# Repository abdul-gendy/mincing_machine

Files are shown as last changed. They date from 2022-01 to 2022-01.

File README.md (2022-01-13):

# mincing_machine
Autodesk fusion 360 assembly of a mincing machine, along with a CAE analysis of some parts in the assembly and a CAM setup for some parts as well

## CAD:
<p align="center">
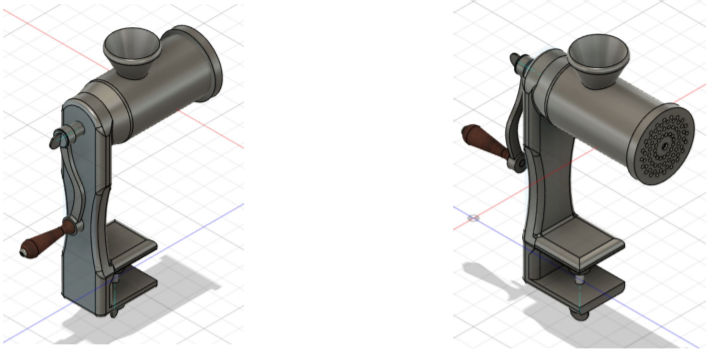
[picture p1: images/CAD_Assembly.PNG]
  
</p>

<p align="center">
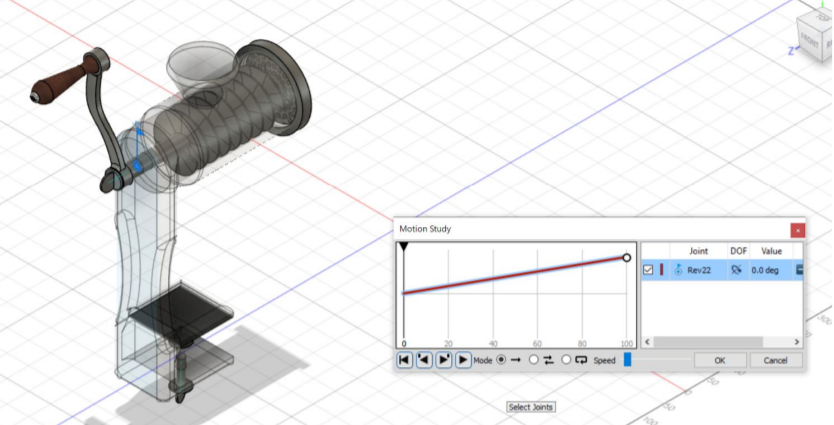
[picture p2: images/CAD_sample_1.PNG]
  
</p>

## CAE:
<p align="center">
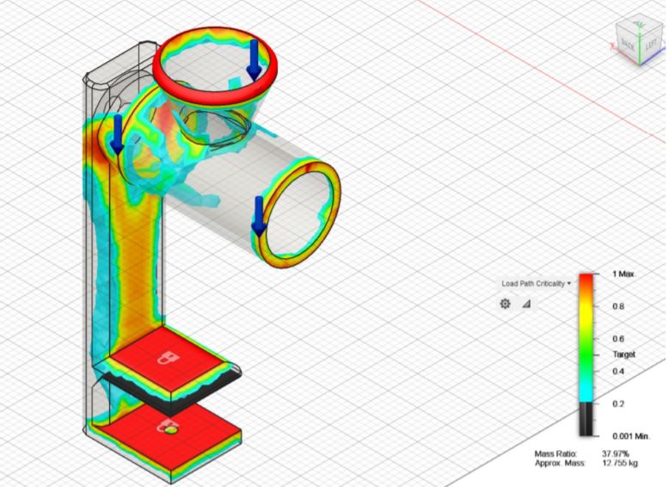
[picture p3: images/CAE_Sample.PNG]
  
</p>

## CAM:
 <p align="center">
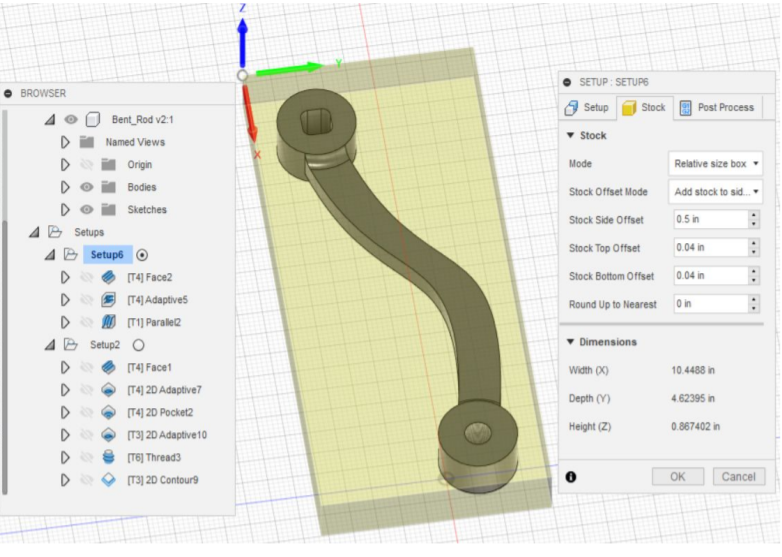
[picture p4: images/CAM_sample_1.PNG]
  
</p>

 <p align="center">
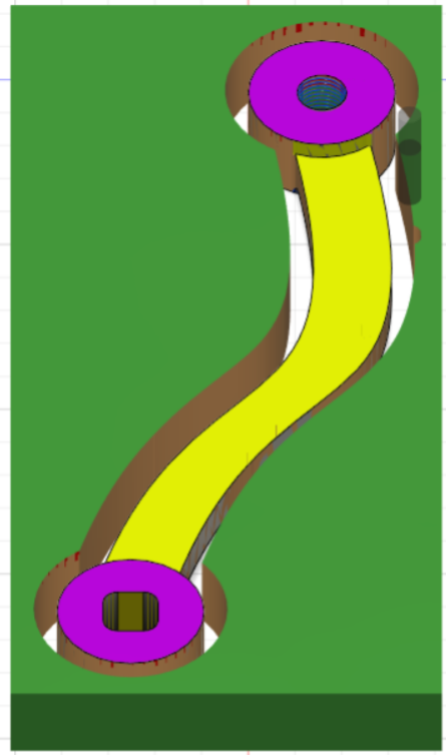
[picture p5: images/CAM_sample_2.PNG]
  
</p>

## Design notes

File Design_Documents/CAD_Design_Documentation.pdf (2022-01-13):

## MECH ENG 4Z03 Design Project

## Group 40

Name | Student Number | Email
Mark Danial | 400066296 | daniam1@mcmaster.ca
Abdulrahman Elgendy | 400051947 | elgendya@mcmaster.ca
Omar Mouftah | 400080124 | mouftaho@mcmaster.ca

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
## Introduction

The assembly we decided to model was that of a meat grinder. We chose this specific tool as it is something simple and basic that many families have, but also is a great example of basic mechanical systems and how they work together. The intended function of the meat grinder is to take some sort of input (usually meat, but can also be vegetables and lentils), and to grind the input together so that it comes out in a soft and ground consistency. The way this works is the user would input the food into the funnel at the top, and rotate the handle which is connected to the auger inside. The auger will then proceed to grind the food together, gradually being pushed towards the end of the tunnel where it will be cut up by a cutting star (or in our case, ninja star). The food then proceeds to get pushed out of the shaping plate at the end, which further breaks down the food into a softer, more grounded consistency. We chose to make most of our design out of stainless steel, as it provides the strong reliable support one can expect from steel but also rusts a lot slower and is easier to clean. These are attributes we deemed important when choosing the material of our meat grinder.

## Design Components Breakdown

Handle

When designing the handle, our main concern was the users comfort. To ensure a comfortable handle, we decided to make it out of mahogany so it has a softer touch and will not get slippery if the user has sweaty hands. The handle was designed to give the user some free space to move their hand while also not wasting too much space, and to provide a solid grip as the user’s main interaction will be with the handle. The modeling was fairly simple. We decided what the dimensions of the handle we wanted were and we drew circles and lines to make a 2D face, then revolved to get the desired shape of the handle.

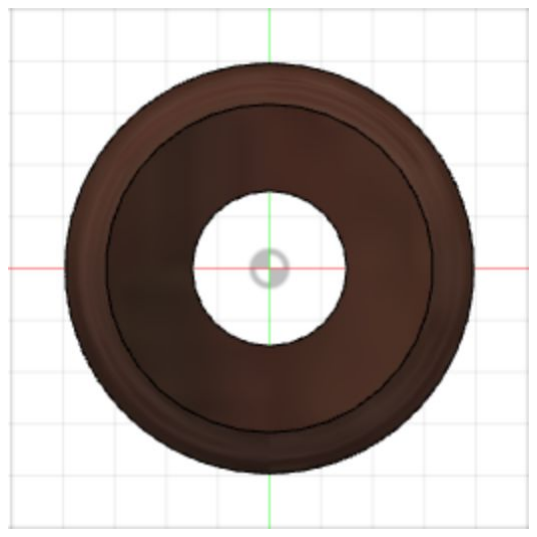
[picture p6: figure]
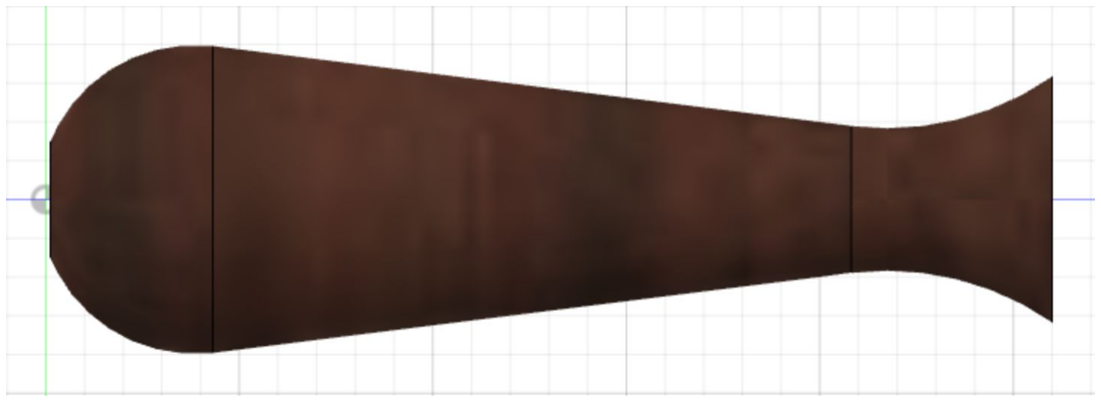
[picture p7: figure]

Handle Pin

The handle pin was a simple part that was needed to connect our handle with our handlebar. It is a simple screw with a thread only at the end of it, this way it can be slid through the wooden handle and screws onto the handlebar. We used a flat head on the screw as it simplifies the design while also getting the desired results. Modelling was simple with just two circle extrusions, a thread, a fillet, and a rectangular extrusion to make the flat head.

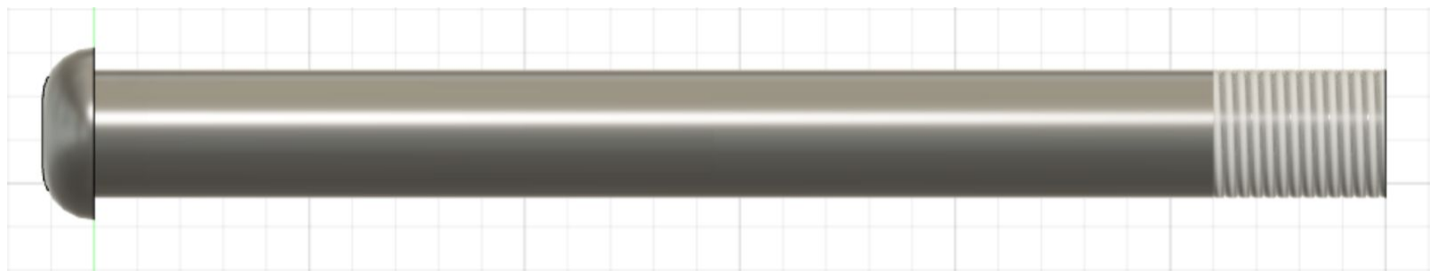
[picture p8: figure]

Handle Bar

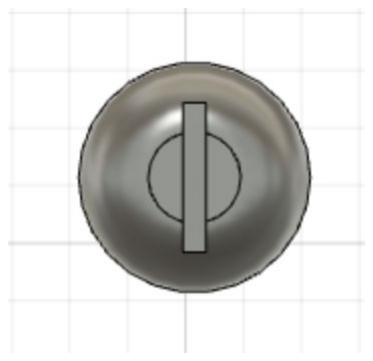
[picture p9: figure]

Next is the handle bar, which is used to connect the handle (through the handle pin) to the auger. This way we are able to translate the rotational motion of the handle to the auger. On the bottom end of the handle bar, the handle pin is screwed into it to connect the handle, while at the top end, the auger’s rounded square end is inserted into it which is connected to the pin. After deciding the length, all that was left was to connect the circular parts at the top of the bottom. A thread was added in the bottom section so that the handle pin can connect the handle with the handlebar. We added fillets on the handlebar to reduce stress concentration, while also adding a sense of style. We decided to use a curved shape to provide some style, which was done by using the fit-point-spline tool.

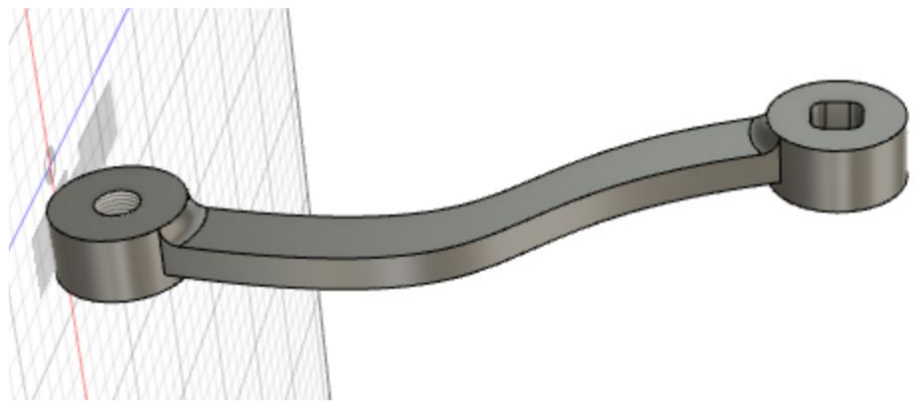
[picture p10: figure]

Auger

Next is the auger, which is the part that the user has the least interaction with but is also the most crucial for the operation of the meat grinder. On one end of the auger, we have the rounded square end that is connected with the handle bar, which is then screwed together using the pin, and the other end lies in the shaper so it has support. Designing the auger was a complicated process as Fusion 360 does not have a helix tool so a more roundabout method was needed. The steps to model the auger were as follows:

1) Extrude Circle to make a cylinder
2) Create a coil (square cross section) with the length of the desired auger with the same diameter as the cylinder, also chose how many revolutions we wanted
3) Create a plane on an angle which was based off of the end of the coil, so that we can draw a rectangle on it which soon become the tooth of the auger
4) Use the “Path + Guide Surface” type Sweep tool along the path of the edge of the coil, which then gives shape to the rectangle we drew earlier
5) Designing the auger itself is done now, just design the endings so that the auger may connect with its counterparts as required

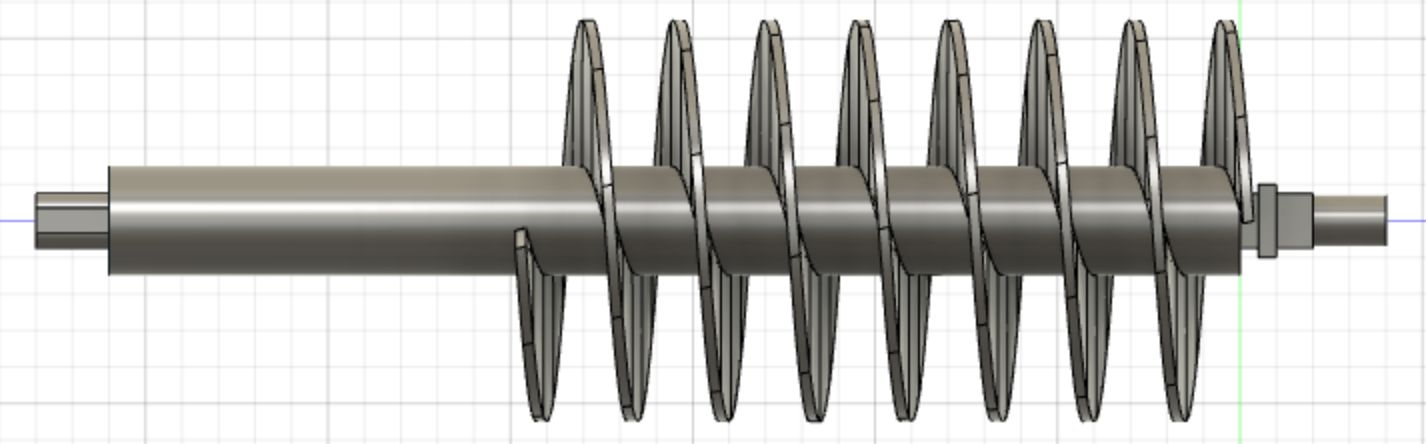
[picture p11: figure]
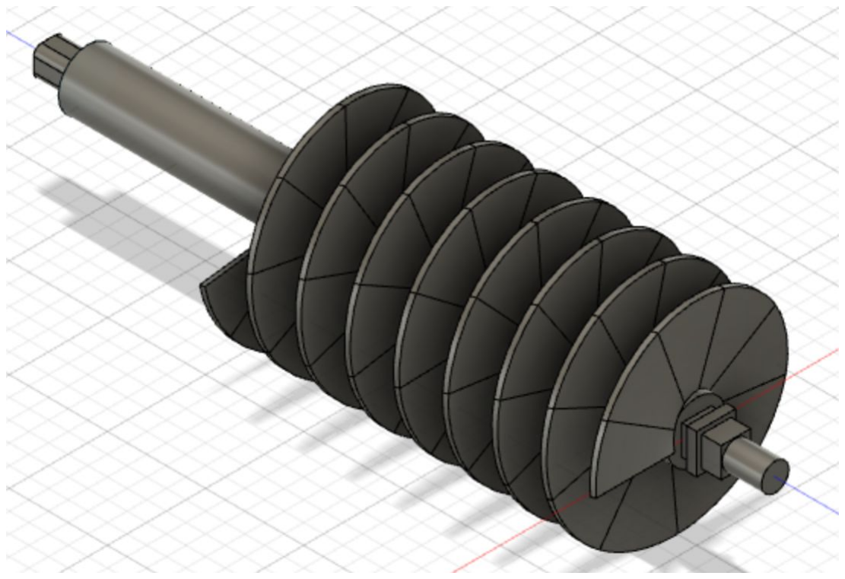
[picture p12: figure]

Pin & Clamp Pin

The pin and the clamp pin are both very similar parts. The key difference is sizing and that the clamp pin has a flat circular surface at the end of the screw, which is meant to get pressed upward onto the surface to provide support for the meat grinder. The pin is used to hold the auger and the handlebar together. Modeling these was very straight forward, we used a few circular extrusions and a fillet, with a thread at the end.

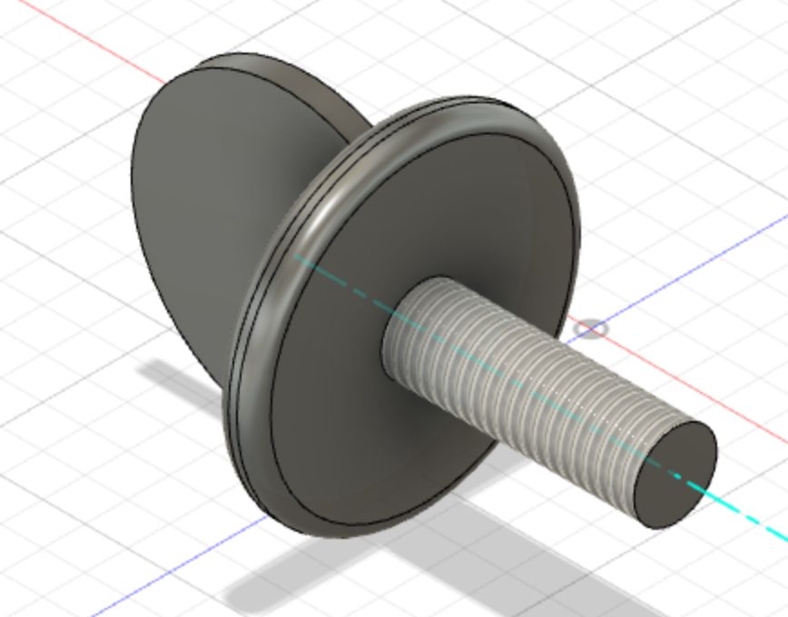
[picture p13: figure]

Body

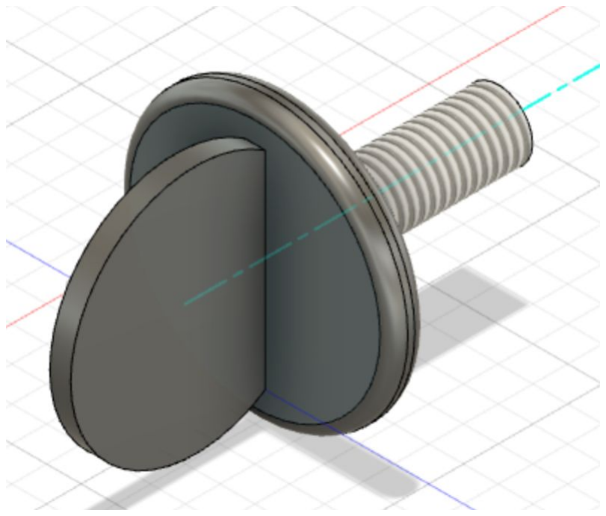
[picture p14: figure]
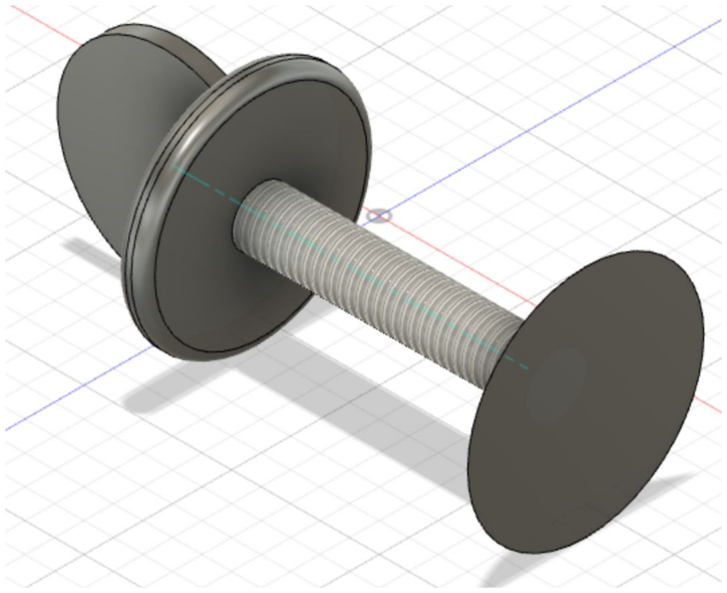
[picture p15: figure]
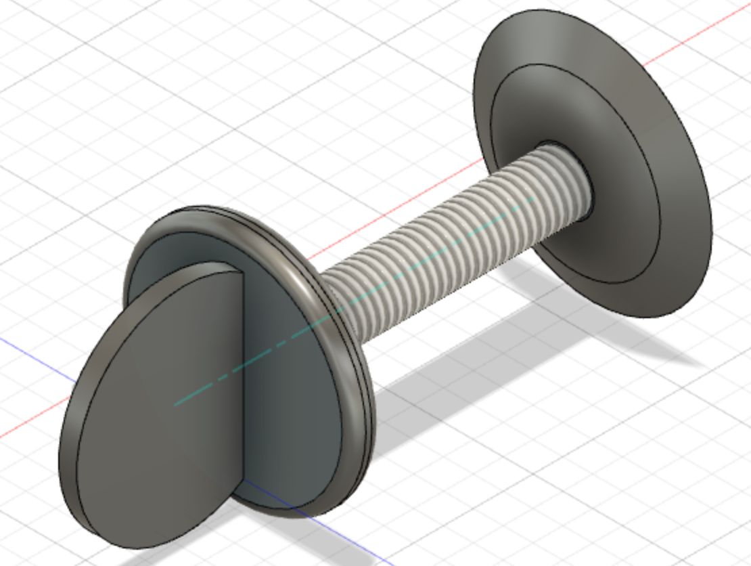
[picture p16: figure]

Next we have the body, which is the largest component in the design. The body connects all the pieces together and houses the auger in the grinding chamber. The body clamps onto the table with the teeth on the top surface and the clamp pin at the bottom. At the top of the grinding chamber there is a cone that the meat is fed into, which then falls into the auger for grinding. At the end of the grinding chamber we have a thread which is used to screw the shaping face onto the body. The body was designed using simple extrusions of basic shapes like circles, rectangles, and triangles (for the teeth), and some lofts to make the grinding chamber and the cone. We chose to add fillets around the body to reduce any edges that may cause cuts since the user will be holding onto the body a lot, and this will also reduce stress concentration.

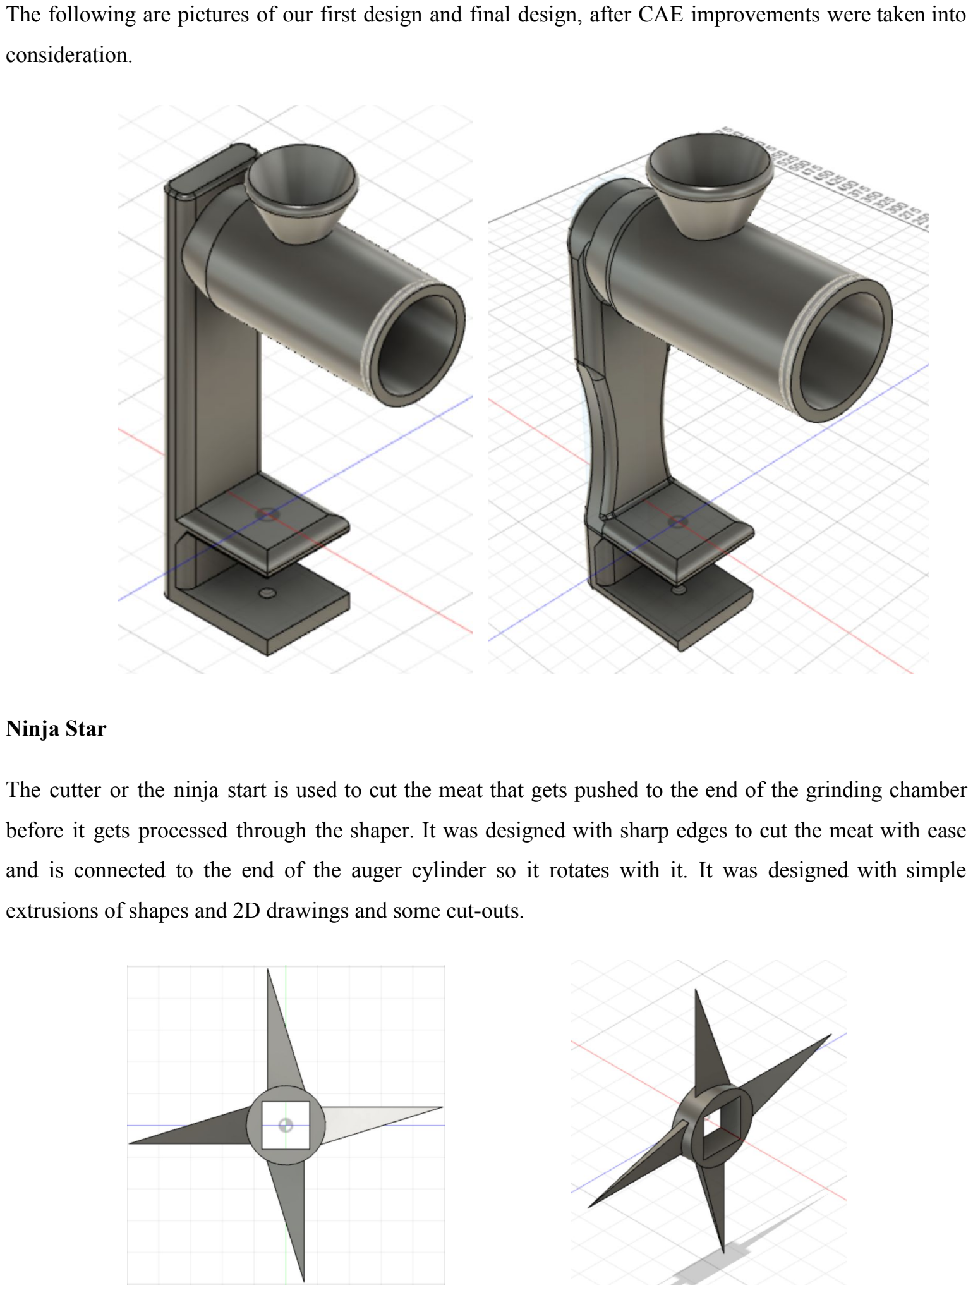
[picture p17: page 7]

The following are pictures of our first design and final design, after CAE improvements were taken into consideration.

Ninja Star

The cutter or the ninja start is used to cut the meat that gets pushed to the end of the grinding chamber before it gets processed through the shaper. It was designed with sharp edges to cut the meat with ease and is connected to the end of the auger cylinder so it rotates with it. It was designed with simple extrusions of shapes and 2D drawings and some cut-outs.

Shaper

Lastly, we have the shaper. The shaper is screwed onto the body at the end of the grinding chamber. The meat is pushed through the grinding chamber by the auger, cut by the ninja star, and then pushed out of the shaper. This is the last phase of processing of the meat and breaks it down into a more refined, ground material. It was designed with simple circle extrusions and a thread on the inner side

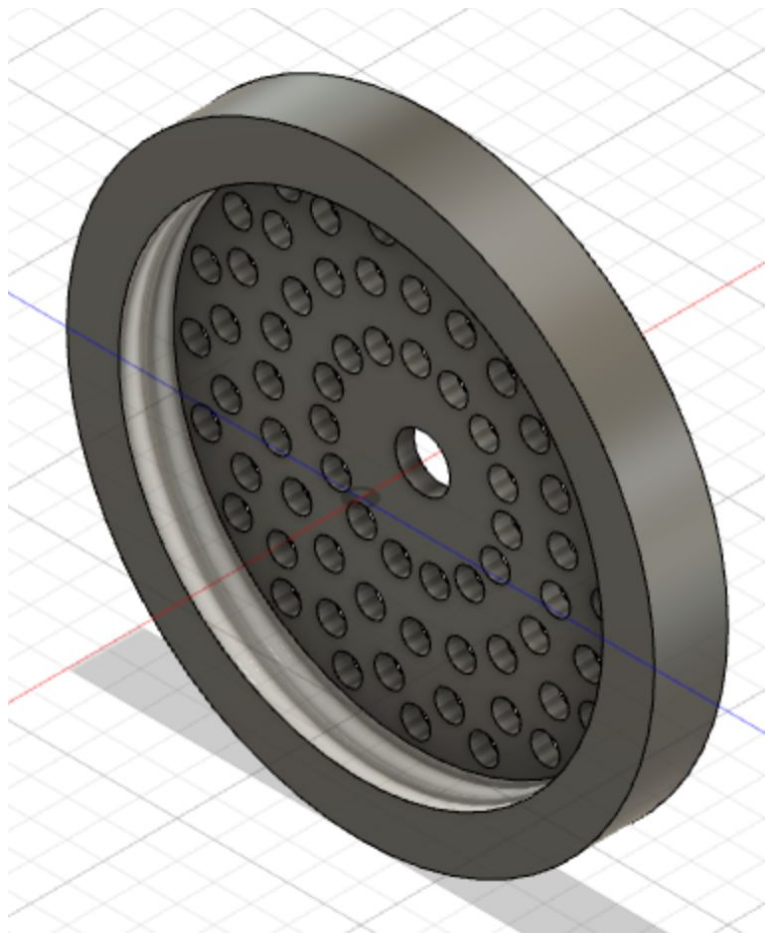
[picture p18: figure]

## Future Improvements

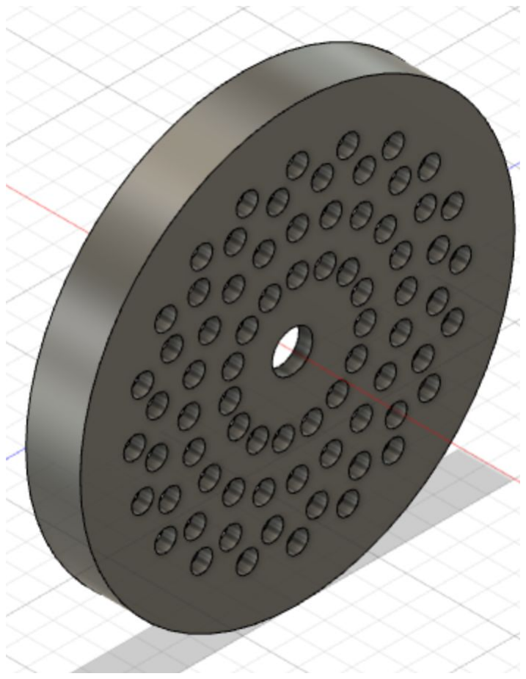
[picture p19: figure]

For a future iteration of the design, we could choose to change several things about the design. One of the things we can look to improve is the size of the grinding chamber. It can be made to hold more/less meat based on feedback from possible users. Another thing we could change is the shapers; We can choose to add more shapers so that the user has the option to choose between different processing sizes for the shaper. Another thing we can look to improve is the handlebar. By choosing a different length and design, we can find an optimal design which would maximize torque and reduce the effort needed by the user.

## Assembly and Dynamic Simulation:

Assembly

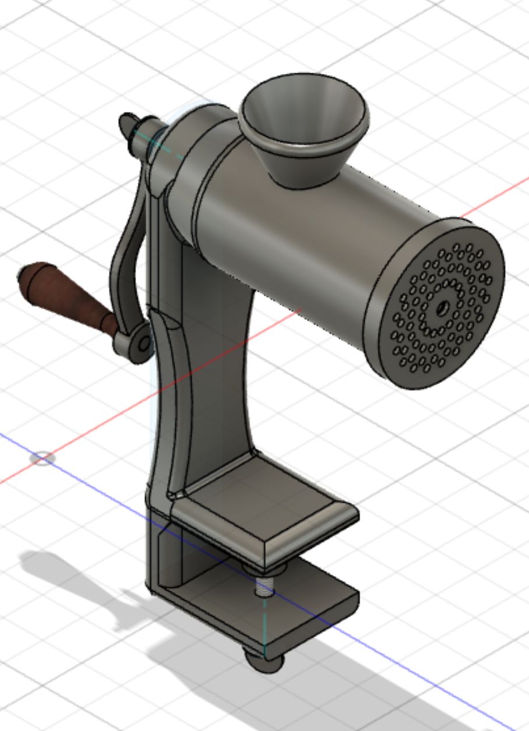
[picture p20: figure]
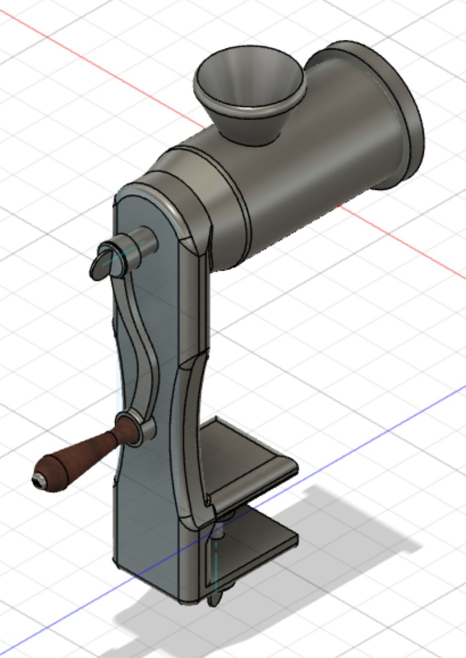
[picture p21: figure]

The views above are of the final assembly with all parts in appropriate positions using joints. A combination of rigid and revolve joints were used in order to ensure proper behaviour when the handle rotates. The handle is linked to the handle pin through a rigid joint to ensure that the pin rotates whenever the handle is moved. There is another rigid joint between the handle pin and the handle bar which is used for the same reason as the first rigid joint. Similarly another rigid joint links between the handle par and the pin. The auger is linked to the body using a revolve joint and to the pin using a rigid constraint, this ensures when the handle moves all the corresponding parts move accordingly including the handle pin, the handle bar, the pin, and the auger. The auger then is linked to the ninja star through another rigid constraint to maintain the same rotation motion. The shaper is linked to the body using a rigid constraint to ensure it does not rotate with the rest of the mechanism. The clamp pin is another part that is linked to the body through a revolve joint to enable the pin from settling in its position based on the width of the table.

Dynamic Simulation

The simulation is available in the motion study section of the assembly and involves moving the main revolve joint that corresponds to the revolving mechanism and observing how parts move accordingly. The screenshots below illustrate the simulation performed. The body is made transparent to a certain degree in order to show the motion of auger and the ninja star inside the meat grinding chamber portion of the body.

Starting Position with handle angle 0 degrees

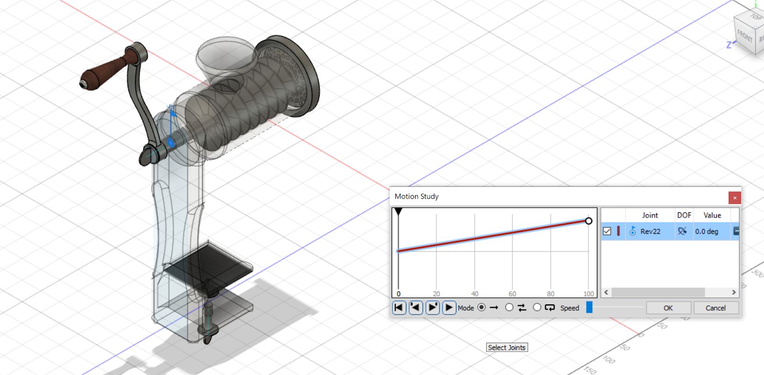
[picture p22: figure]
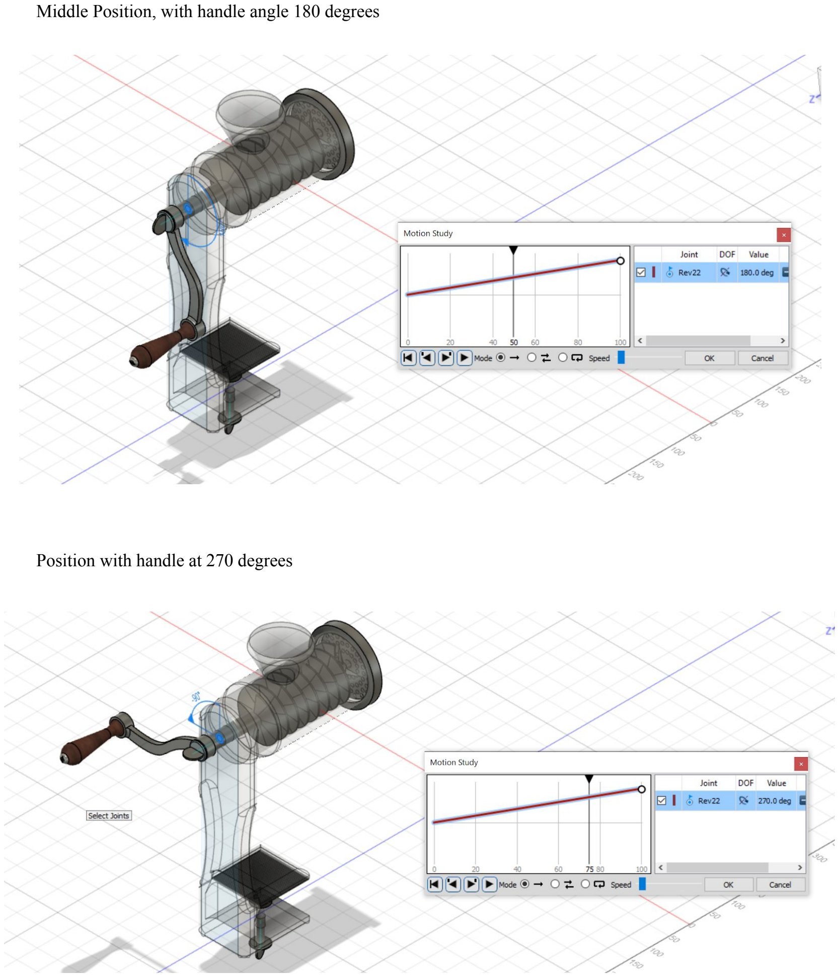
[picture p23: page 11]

Middle Position, with handle angle 180 degrees

Position with handle at 270 degrees

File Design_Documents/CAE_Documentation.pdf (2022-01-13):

## Computer Aided Engineering

Part 1 - Body

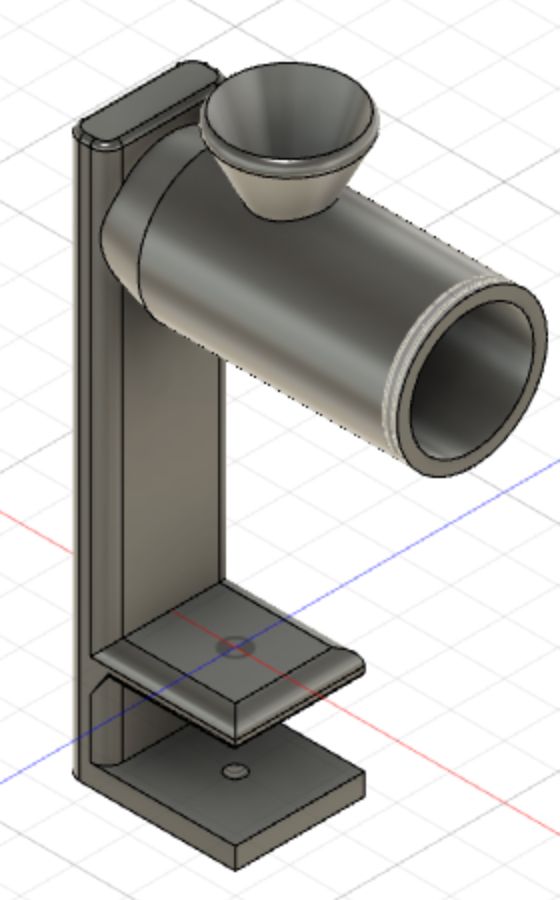
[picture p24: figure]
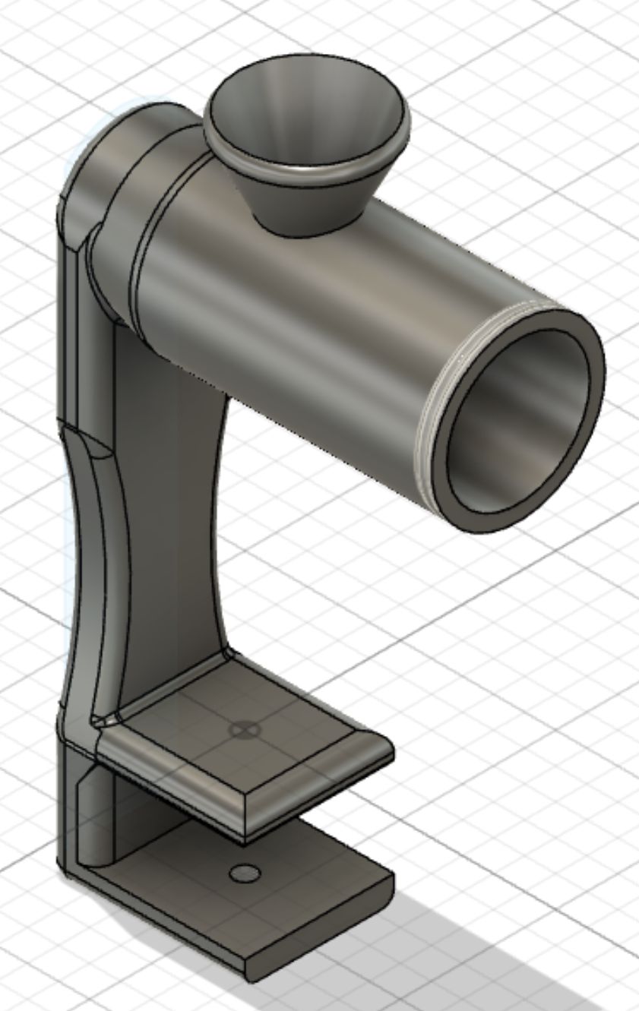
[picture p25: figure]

The body of the meat grinder is one of the most critical parts as it contains the entire mechanism and is exposed to the most loads due to its size. The design on the left was the initial design for the body. While material usage and optimization were taken into account during the preliminary design stage, the CAE analysis revealed that there were still areas of improvements through material reductions. The mass for the initial body part was around 34 kg, however, after shape optimization and reduction of unneeded material the mass for the modified body part was 30 kg which is a reduction of more than 12 %. The loading for the part was over exaggerated at 1500 N which is an arbitrary heavy load which the body of the meat grinder is unlikely to get exposed to. The loads were applied at three areas, the first and second are at the beginning and end of the grinding chamber and are placed to simulate a user's hand applying a force to keep the body in place while grinding. The third load is to simulate the load resulting from the ungrinded meat in the cone area of the body. In addition, fixed constraints are placed on the two bottom faces of the body as they will be secured to the table using the clamp pin.

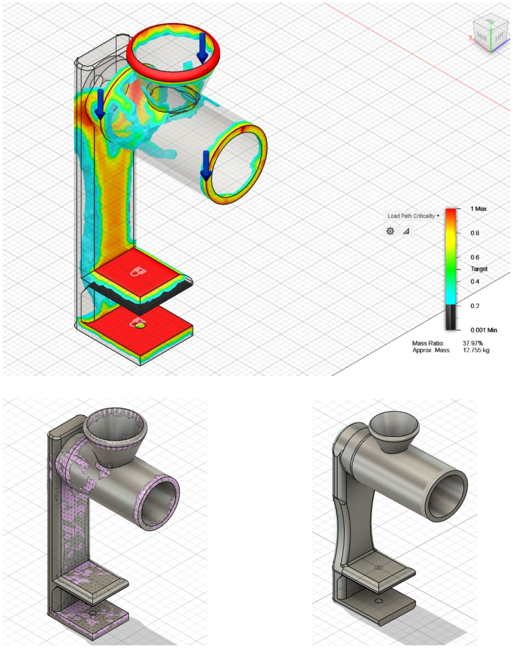
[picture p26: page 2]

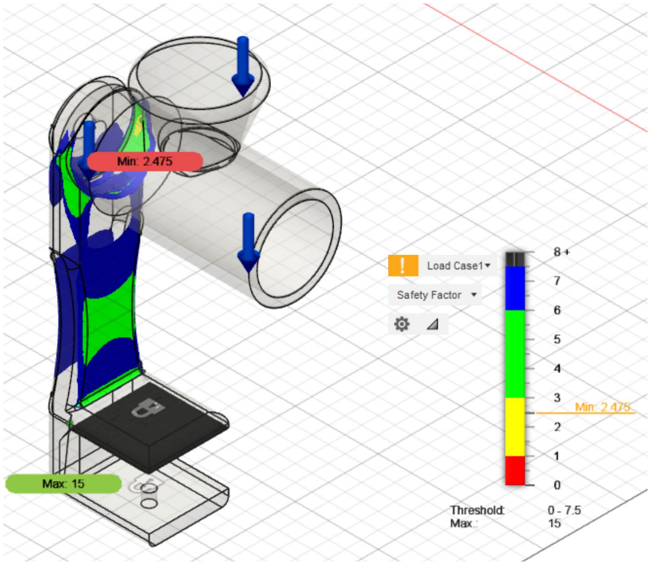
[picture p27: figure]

As seen from the results of the stress analysis, the material reduction did not affect the structural integrity of the body as it was able to handle the over estimated load of 1500 N with a minimum safety factor of safety of 2.475 which is suitable for a product that is not safety critical like a meat grinder. The loads are overestimated in order to test how the part would handle extreme loads after the part’s optimization.

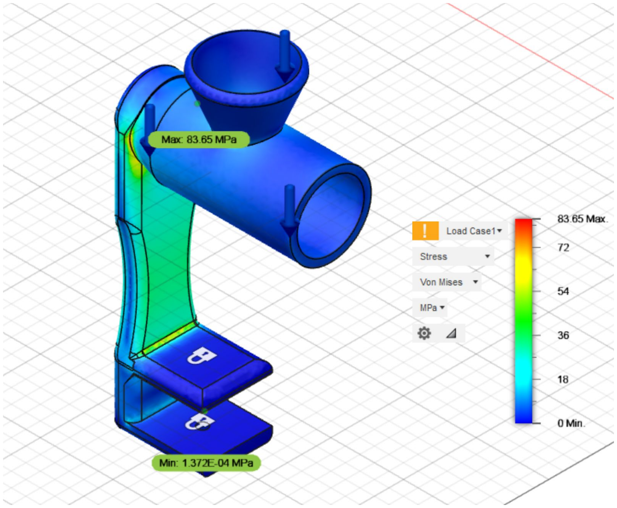
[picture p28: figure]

The von mises stress chart confirms the results from the safety factor chart as it shows maximum stress at the edge where the grinding chamber meets the remainder of the body. This edge is expected to have the maximum stress due to part geometry and the location the load is placed at. An improvement in the design would be changing the force at that edge to cover a larger area and thus reduce the stress concentration on that edge, however taking into account the excessive load that the test is placing on the part, the factor of safety and the maximum von mises stress seem to be within acceptable levels.

Part B - Shaper

While the shape optimization analysis was useful when conducted on the body part of the assembly the shaper is an example of a part which the shape optimization simulation was not useful and did not result in a change in the part design. The load that the shaper experiences is a result of all the meat being pushed by the auger. This load was simulated by an over estimated by a constant 1500 N force over the inside face of the shaper. The fixed constraint associated with the shaper is on the inside area that is fixed to the body part and thus does not move as part of the rotating mechanism.

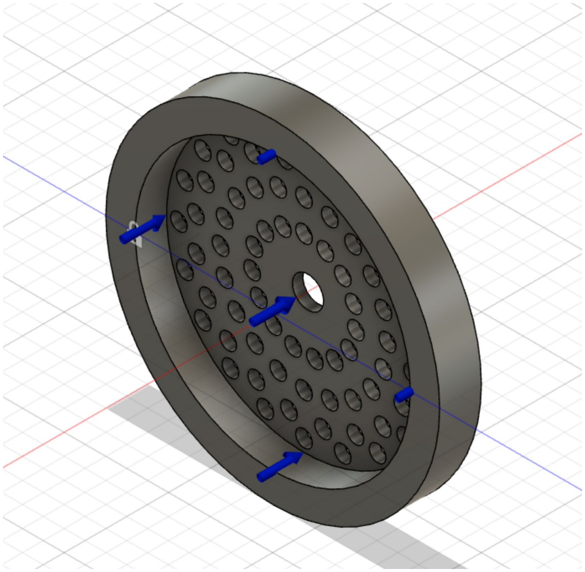
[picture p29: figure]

The results of the shape optimization simulation are the following:


This shows that the material that is not needed according to the simulation is required in order to assemble the shaper with the body part and as any material removal form the edge might affect the neshing between the threads in the shaper and the threads on the end of the grinding chamber in the body part. Furthermore, the amount of material to be removed based on the simulation results will not be significant enough to justify removing it from an economic standpoint and as a result a decision was made to keep the part in its initial form and perform the stress analysis on the preliminary design.

The stress analysis was done using the same load and constraints used in the shape optimization analysis. The load was also over exaggerated at 1500 N in order to simulate a very excessive condition on the part. The shaper part performed very well under the experienced load as the minimum factor of safety was 7.4 which means that the part can handle much higher loads than the simulated 1500 N. The charts below show the effect of the load in adjusted view to overstate the deformation of the part under the load. This analysis shows that the part in its initial format without modification was able to handle the forces that the part will be exposed to.


The von mises analysis shows that the maximum stress occurs at the holes of the shaper which is a result of the force from the meat hitting the sharp edge of the shaper to be cut into the appropriate shape. The von mises chart shows that even that those sharp edges exist for meat cutting the maximum stress is 29.4 MPa which is within an acceptable range as it does not cause the material to yield or plastically deform since Stainless Steel has a yield strength of 250 MPa and an ultimate tensile strength of 540 MPa which are both way below the maximum stress that the part experiences.

CAE Discussion:

Throughout this project the CAE analysis, we faced some issues with the mesh sizing and solving the simulation as there were many issues that required debugging as well as trial and error. At the end of this debugging process it was realized that the optimal mesh size for solving and avoiding errors is 2%. This information would have been crucial at the beginning as many hours were wasted in order to debug why solutions were facing solving errors when running shape optimization or stress analysis.

## 2D Component Drawings


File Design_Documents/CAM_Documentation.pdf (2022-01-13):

## Computer Aided Manufacturing

Part 1 - Handle Bar

The stock size was created to have a 0.5 inches offset on the sides, and a 0.04 inches offset on the top and bottom as shown below. This extra 0.5 inches in the stock allows the vice to firmly grip onto the stock during machining. We have two setups ready for this CAM demonstration. The operations in the first setup are performed on the top face of the stock that is shown below, and the operations in the second setup are performed on the bottom face of the stock. The strategy that will be used to machine this part is:

Top view operations:


1. Firstly, a 2D face operation was performed using a ⅛” flat end mill to prepare the raw stock for machining.


2. The next step would be to use 3D adaptive clearing to rough out large quantities of material in the middle segment of the Handle bar, with a maximum roughing stepdown of 0.05 inches. This prevents the tool from cutting the entire depth at once. This was done using a ⅛” flat end mill


3. Finally, we used the parallel operation as a finishing operation on the ramps that are on the handle bar. This operation involved using a ⅛” ball end mill while using a really small stepover of 0.005 inches to ensure a smooth transition of the ball end mill over the surface.


Bottom view operations:

1. After flipping the stock to its bottom side, we performed a 2D face operation using a ⅛” flat end mill to prepare the bottom of the stock for machining.

2. We Used the 2D adaptive clearing operation to rough out large quantities of material in the middle segment of the Handle bar, with a maximum roughing stepdown of 0.05 inches as well. This prevents the tool from cutting the entire depth at once. Please note that the bottom side of the handle bar does not have the ramps that were shown on the top view.This was done using a ⅛” flat end mill


3. The next step would be a 2D pocket operation using a ⅛” flat end mill on the filleted square pocket with a maximum roughing stepdown of 0.05 inches.


4. The following step would be a 2D adaptive operation using a ¼” flat end mill to clear out the hole before threading it. The required thread has a M15 x 1.5 designation, which means the pitch is 0.0590551 inches. Our required thread percentage is 75%. Therefore, our required minor diameter is 13.526mm (0.532519685 in) , and our required major diameter is 15mm (0.590551 in). This operation will clear out the hole to our required minor diameter of 13.526mm


5. The following step would be a threading operation on the hole that we just created in the step before. We are going to use a thread mill shown in the list of tools below. The thread pitch would be 0.0590551 inches and the pitch diameter offset which is the difference between the major diameter and minor diameter is 0.058032 inches.


6. The final operation would be a 2D contour to separate the manufactured handle bar from the excess stock while leaving Two tabs behind to prevent the part from breaking free during the machining process. The maximum roughing stepdown was set to 0.1 inches to prevent the tool from cutting through the entire depth at once. The tool used a ¼” flat end mill.

The following tools were used to machine the handle bar:

The results of the simulation can be seen below:



Part 2 - Shaper

The stock setup for the shaper part was created to have a 0.5 inches offset on the sides, and a 0.04 inches offset on the top and bottom as shown below. This extra 0.5 inches in the stock allows the vice to firmly grip onto the stock during machining. We have two setups ready for this CAM demonstration. The operations in the first setup are performed on the bottom face of the stock that is shown below, and the operations in the second setup are performed on the top face of the stock.


Bottom view operations:

1. Firstly, a 2D face operation was performed using a ⅛” flat end mill to prepare the raw stock for machining.


2. The following step would be a 2D adaptive operation using a ¼” flat end mill to clear out the hole before threading it. A maximum roughing stepdown of 0.1 inches was used to prevent the tool from cutting the entire depth at once. The required thread has a M140 x 8 designation, which means the pitch is 0.315 inches. Our required thread percentage is 75%. Therefore, our required minor diameter is 5.191 inches , and our required major diameter is 140mm (5.51181 in). This operation will clear out the hole to our required minor diameter of 5.191 inches.


3. The following step would be a threading operation on the hole that we just created in the step before.We are going to use a thread mill shown in the list of tools below. The thread pitch would be 0.315 inches and the pitch diameter offset which is the difference between the major diameter and minor diameter is 0.32 inches.

Top view operations:


1. After flipping the stock to its top side, we performed a 2D face operation using a ⅛” flat end mill to prepare the top of the stock for machining.
2. The next step would be a 2D pocket operation using a ⅛” flat end mill on the 76 holes that are on the top of the shaper.


3. The final operation would be a 2D contour to separate the manufactured handle bar from the excess stock while leaving Three tabs behind to prevent the part from breaking free during the machining process. The maximum roughing stepdown was set to 0.1 inches to prevent the tool from cutting through the entire depth at once. The tool used a ¼” flat end mill.

The following tools were used to machine the handle bar:

The results of the simulation can be seen below:


One of the main difficulties encountered in this CAM demonstration was machining the ramped area on the handle bar. The ball end mill that we used for surface finishing kept milling into the middle segment that was not part of the ramp, making it really hard to machine a very accurate ramp. To try and address that, we tried using the “avoid/touch surfaces” feature under the parallel operation to try and constrict the toolpath of the ball end mill to be strictly within the ramp. One other problem that we encountered with the ramp was that the ball end mill was missing the sides of the ramp. This left a lot of rough edges at the sides of the ramp. To try and fix that, we decided to add an offset to the tool containment to try and cover the sides of the ramp that the tool was not able to reach. Another issue was the threading inside the shaper part. The diameter of that threaded hole was really big, making it really hard to work with using a threaded mill with a small diameter. Something we learned from the CAM development was that some tabs need to be left in place to attach the part to the extra stock to make sure that the part doesn't break free during machining. To reduce machining time we would probably get rid of the ramp on the bar handle as it does not serve a very important mechanical role, as it is costing a lot of machining time with its rough and finishing operations. Another thing we can do to reduce the machining time is manually threading the hole in the handle bar, as we save some machine power and machining time doing so.

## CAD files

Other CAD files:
CAD/Assembly v1.f3z
CAD/Auger v2.f3d
CAD/BODY v2.f3d
CAD/Bent_Rod v1.f3d
CAD/Handle v0 v1.f3d
CAD/HandlePin v2.f3d
CAD/Ninja_Star v2.f3d
CAD/Pin v1.f3d
CAD/SHAPER v1.f3d
CAE/Initial_Body_CAE.f3d
CAE/SHAPER_CAE.f3d
CAE/Updated_Body_CAE.f3d
CAM/Handle_Bar_CAM.f3d
CAM/SHAPER_CAM.f3d
